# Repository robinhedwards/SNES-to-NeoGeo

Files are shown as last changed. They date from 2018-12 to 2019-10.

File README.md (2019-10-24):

SNES to Neo Geo
===============

This is an Arduino project which allows you to interface a SNES or Super Famicom controller
(or a clone) to a Neo Geo style DB15 connector.

I created this for my CMVS project (consolizing a MVS Neo Geo arcade motherboard), and I had
some nice, working SNES controllers that I wanted to use. SNES controllers are quite a good fit
for the Neo Geo because the button colours match (well, except on the purple USA ones!).

It looked easy enough to rewire the controllers and attach a new socket, but I wanted something
that left them in their original state so I could still use them on my SNES.

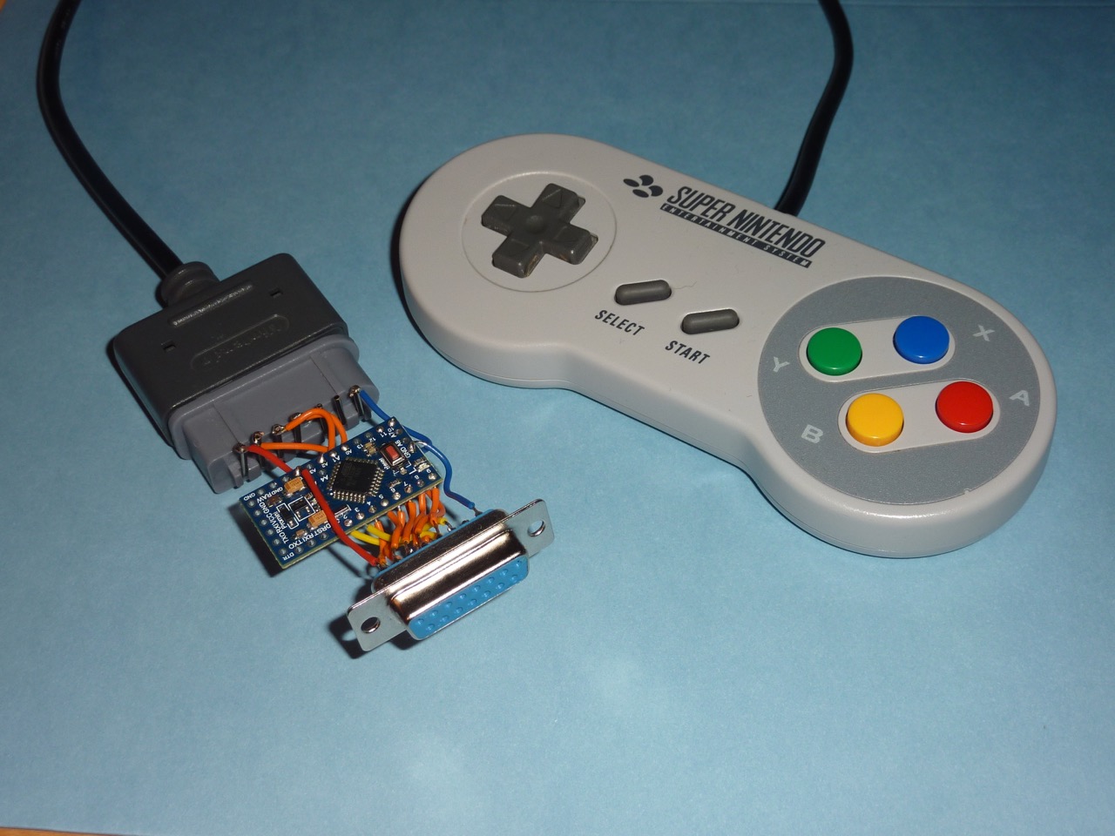
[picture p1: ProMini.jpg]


This shows a completed project on a cheap Arduino Pro Mini (5v) clone wired up to a SNES female
socket and female DB15 for easy connections.

SNES female controller sockets are available on eBay for a couple of pounds, and a Pro Mini
clone costs about the same, so the total cost of the project is only about five pounds.

SNES Controller -> Arduino
--------------------------

```
  -----------------\
  | 1 2 3 4 | 5 6 7 |
  -----------------/
  
  Pin 1: +5V
  Pin 2: Clock -> Arduino A0
  Pin 3: Latch -> Arduino A1
  Pin 4: Serial -> Arduino A2
  Pin 7: GND
```

Arduino -> DB15
---------------

```
    1(=GND)        8(=5V)
  \-------------------/
   \ o o o o o o o o / [Viewed from front]
    \ o o o o o o o /
     --------------- 
      9          15

 DB15 Pin  ->  Arduino
 --------      -------
 1 (GND)       GND
 8 (+5V)       +5V
 3 (Sel)       D2
 11 (Start)    D3
 15 (Up)       D4
 7 (Down)      D5
 14 (Left)     D6
 6 (Right)     D7
 13 (A)        D8
 5 (B)         D9
 12 (C)        D10
 4 (D)         D11
```

3d printed case
---------------

I've designed a simple box for the device that can be 3d printed. It fits the Pro Mini inside
along with the SNES socket and a cable grip for a DB15 cable.

The case is designed to fit a cable grip extracted from a UK mains plug (with 16mm spacing between
the grip screws).

The STL files are included here along with the source SCAD files if you need to make any tweaks to
the design.

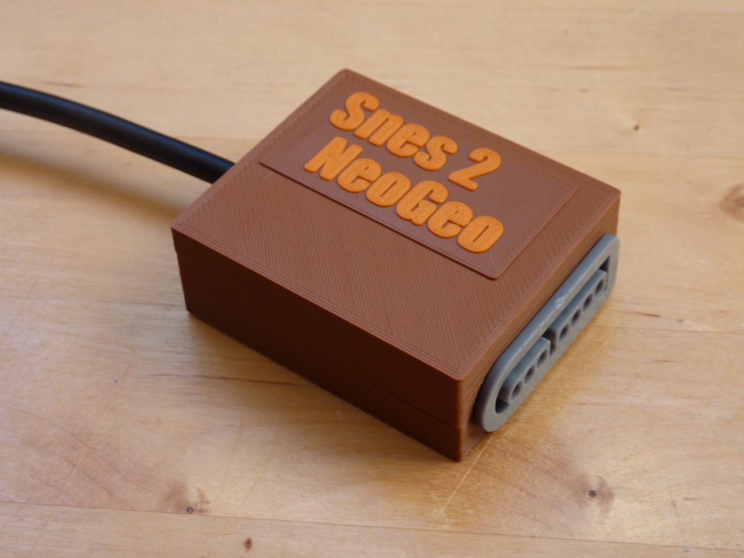
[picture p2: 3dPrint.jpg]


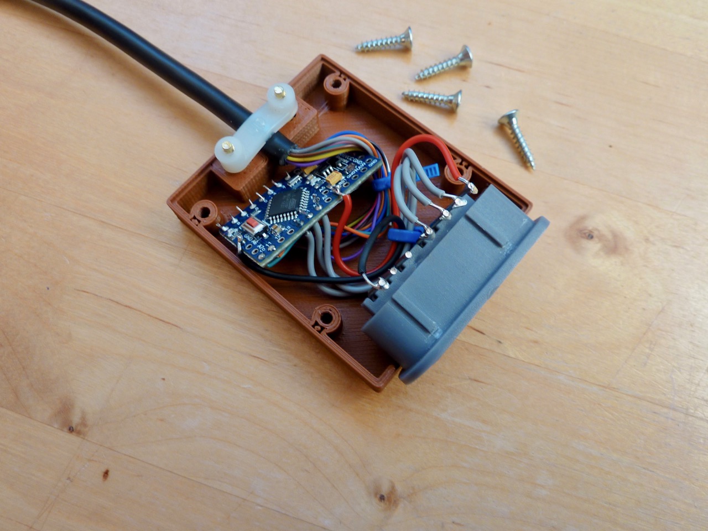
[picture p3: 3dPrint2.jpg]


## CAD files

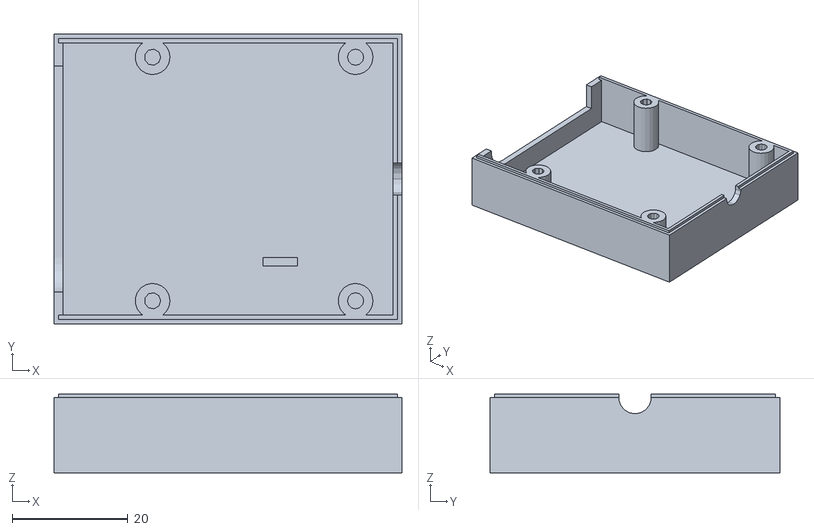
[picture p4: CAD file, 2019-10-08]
3d printing files/Snes2Neo_top.stl
60.0 x 50.0 x 13.6

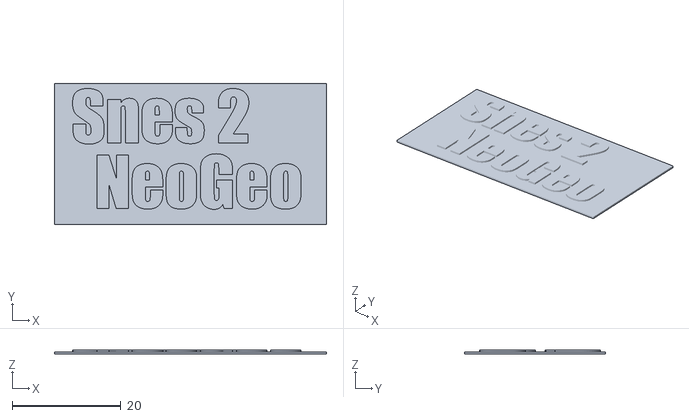
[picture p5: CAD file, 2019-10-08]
3d printing files/Snes2Neo_logo.stl
50.0 x 26.0 x 0.8

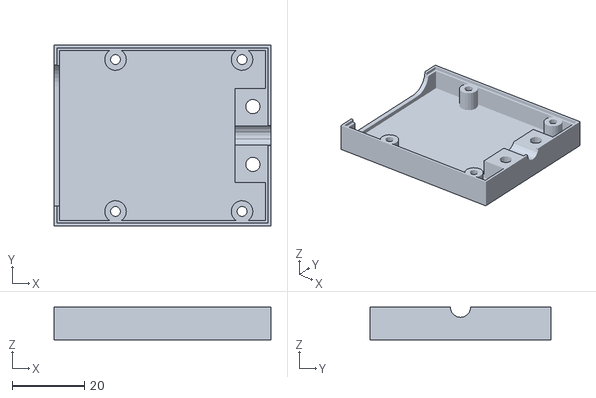
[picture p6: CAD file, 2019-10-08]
3d printing files/Snes2Neo_bottom.stl
60.0 x 50.0 x 9.00

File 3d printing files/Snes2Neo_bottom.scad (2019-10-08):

/* Snes 2 Neo Geo DB15 shell (bottom)
   (c) R.Edwards 2019
*/

cart_length=60; // 60
cart_width=50;
cart_height=9;
screw_sep = 39.5;
front_thickness = 1.6;
sides_thickness = 1.6 - 0.05;
rim_height = 1;
port_width = 39;
port_height = 12;
screw_radius = 3;
screw_from_edge = 1;

difference() {
    union() {
        difference() {
            // main shell
            cube([cart_length, cart_width, cart_height]);
            // rims
            translate([sides_thickness/2, sides_thickness/2, cart_height-rim_height])
                cube([cart_length-sides_thickness,
                    cart_width-sides_thickness, rim_height]);
            // make hollow
            translate([sides_thickness, sides_thickness, front_thickness])
                cube([cart_length-sides_thickness*2,
                    cart_width-sides_thickness*2,
                    cart_height-front_thickness]);
            // cutout snes port
            translate([0, (cart_width - port_width)/2, cart_height - port_height/2])
                translate([-sides_thickness/2, 0, 0])
                    union() {
                        cube([sides_thickness*2, port_width-port_height/2, port_height]);
                        translate([0,0,port_height/2])
                            rotate([0,90,0]) {
    //                            cylinder(h = sides_thickness*2, r1 = port_height/2, r2 = port_height/2,  $fs = 1);
                                translate([0, port_width-port_height/2, 0])
                                    cylinder(h = sides_thickness*2, r1 = port_height/2, r2 = port_height/2,  $fs = 1);
                            }
               }
        }
        translate([17, cart_width-screw_radius-screw_from_edge, 0])
            difference() {
                cylinder(h = cart_height-rim_height, r1 = screw_radius, r2 = screw_radius,  $fs = 1);
                cylinder(h = cart_height-rim_height, r1 = 1.8, r2 = 1.4,  $fs = 1);
            }
        translate([17, screw_radius+screw_from_edge, 0])
            difference() {
                cylinder(h = cart_height-rim_height, r1 = screw_radius, r2 = screw_radius,  $fs = 1);
                cylinder(h = cart_height-rim_height, r1 = 1.8, r2 = 1.4,  $fs = 1);
            }
        translate([52, cart_width-screw_radius-screw_from_edge, 0])
            difference() {
                cylinder(h = cart_height-rim_height, r1 = screw_radius, r2 = screw_radius,  $fs = 1);
                cylinder(h = cart_height-rim_height, r1 = 1.8, r2 = 1.4,  $fs = 1);
            }
        translate([52, screw_radius+screw_from_edge, 0])
            difference() {
                cylinder(h = cart_height-rim_height, r1 = screw_radius, r2 = screw_radius,  $fs = 1);
                cylinder(h = cart_height-rim_height, r1 = 1.8, r2 = 1.4,  $fs = 1);
            }
        // cable grip
        translate([50, (cart_width-26)/2, 0])
            cube([cart_length-50, 26, cart_height-rim_height]);
    }
    // cutout cable hole
    translate([cart_length-20, cart_width/2, cart_height])
        rotate([0,90,0])
            cylinder(h = 20, r1 = 2.8, r2 = 2.8,  $fs = 1);
    // screw top
    translate([17, cart_width-screw_radius-screw_from_edge, 0])
        cylinder(h = 0.6, r1 = 3.5, r2 = 3.5,  $fs = 1);
    translate([17, cart_width-screw_radius-screw_from_edge, 0.6])
        cylinder(h = front_thickness-0.6, r1 = 3.5, r2 = 1.8,  $fs = 1);
    translate([17, screw_radius+screw_from_edge, 0])
        cylinder(h = 0.6, r1 = 3.5, r2 = 3.5,  $fs = 1);
    translate([17, screw_radius+screw_from_edge, 0.6])
        cylinder(h = front_thickness-0.6, r1 = 3.5, r2 = 1.8,  $fs = 1);
    translate([52, cart_width-screw_radius-screw_from_edge, 0])
        cylinder(h = 0.6, r1 = 3.5, r2 = 3.5,  $fs = 1);
    translate([52, cart_width-screw_radius-screw_from_edge, 0.6])
        cylinder(h = front_thickness-0.6, r1 = 3.5, r2 = 1.8,  $fs = 1);
    translate([52, screw_radius+screw_from_edge, 0])
        cylinder(h = 0.6, r1 = 3.5, r2 = 3.5,  $fs = 1);
    translate([52, screw_radius+screw_from_edge, 0.6])
        cylinder(h = front_thickness-0.6, r1 = 3.5, r2 = 1.8,  $fs = 1);
    // holes for cable grip
    translate([55, cart_width/2-8, 0])
        cylinder(h = cart_height-rim_height, r1 = 2, r2 = 2,  $fs = 1);
    translate([55, cart_width/2+8, 0])
        cylinder(h = cart_height-rim_height, r1 = 2, r2 = 2,  $fs = 1);
    // screw tops
    translate([55, cart_width/2-8, 0])
        cylinder(h = 0.6, r1 = 3.5, r2 = 3.5,  $fs = 1);
    translate([55, cart_width/2-8, 0.6])
        cylinder(h = front_thickness-0.6, r1 = 3.5, r2 = 2,  $fs = 1);
    translate([55, cart_width/2+8, 0])
        cylinder(h = 0.6, r1 = 3.5, r2 = 3.5,  $fs = 1);
    translate([55, cart_width/2+8, 0.6])
        cylinder(h = front_thickness-0.6, r1 = 3.5, r2 = 2,  $fs = 1);
    
}
//            cylinder(h = sides_thickness, r1 = port_height/2, r2 = port_height/2,  $fs = 1);

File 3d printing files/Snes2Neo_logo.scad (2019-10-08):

/* SNES2Neo shell top (logo)
   (c) R.Edwards 2018
*/

width=50;
height=26;
thickness=0.4;

union() {
    translate ([3,15,thickness]) {
        linear_extrude(height = 0.4) {
            text("Snes 2", font = "Impact:style=Regular", size = 9);
        }
    }
    translate ([3,3,thickness]) {
        linear_extrude(height = 0.4) {
            text("  NeoGeo", font = "Impact:style=Regular", size = 9);
        }
    }
    cube([width, height, thickness]);
}

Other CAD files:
3d printing files/Snes2Neo_top.scad

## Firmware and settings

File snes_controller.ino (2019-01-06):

/*
SNES -> Jamma/Neo Geo DB15
Robin Edwards 2018
based on the code found at https://github.com/burks10/Arduino-SNES-Controller
*/

/* 

SNES Controller -> Arduino
  -----------------\
  | 1 2 3 4 | 5 6 7 |
  -----------------/
  
  Pin 1: +5V
  Pin 2: Clock -> Arduino A0
  Pin 3: Latch -> Arduino A1
  Pin 4: Serial -> Arduino A2
  Pin 7: GND
*/

int DATA_CLOCK    = A0;
int DATA_LATCH    = A1;
int DATA_SERIAL   = A2;

/* 

Arduino -> DB15
    1(=GND)        8(=5V)
  \-------------------/
   \ o o o o o o o o / [Viewed from front]
    \ o o o o o o o /
     --------------- 
      9          15

 DB15 Pin  ->  Arduino
 --------      -------
 1 (GND)       GND
 8 (+5V)       +5V
 3 (Sel)       D2
 11 (Start)    D3
 15 (Up)       D4
 7 (Down)      D5
 14 (Left)     D6
 6 (Right)     D7
 13 (A)        D8
 5 (B)         D9
 12 (C)        D10
 4 (D)         D11
*/

#define PIN_SELECT  2
#define PIN_START   3
#define PIN_UP      4
#define PIN_DOWN    5
#define PIN_LEFT    6
#define PIN_RIGHT   7
#define PIN_BUT1    8
#define PIN_BUT2    9
#define PIN_BUT3    10
#define PIN_BUT4    11

#define PIN_LED      13

int buttons_state[12];  // B,Y,Sel,Start,U,D,L,R,A,X,L,R
int output_pins[12] = { PIN_BUT2, PIN_BUT3, PIN_SELECT, PIN_START, PIN_UP, PIN_DOWN,
                        PIN_LEFT, PIN_RIGHT, PIN_BUT1, PIN_BUT4, 0, 0 };
void setup ()
{
    pinMode(DATA_CLOCK, OUTPUT);
    digitalWrite (DATA_CLOCK, HIGH);
  
    pinMode(DATA_LATCH, OUTPUT);
    digitalWrite(DATA_LATCH, LOW);
    
    pinMode(DATA_SERIAL, INPUT_PULLUP);
    
    pinMode(PIN_LED, OUTPUT);
}

void loop ()
{
    // Read from the SNES controller
    
    /* Latch for 12us */
    digitalWrite(DATA_LATCH, HIGH);
    delayMicroseconds(12);
    digitalWrite(DATA_LATCH, LOW);
    delayMicroseconds(6);
    
    /* Read data bit by bit from SR */
    for (int i = 0; i < 16; i++) {
        digitalWrite(DATA_CLOCK, LOW);
        delayMicroseconds(6);
        if (i <= 11)
            buttons_state[i] = digitalRead(DATA_SERIAL);
        digitalWrite(DATA_CLOCK, HIGH);
        delayMicroseconds(6);
    }
    
    // Output the state on our DB15 output pins
    // pulling them low if the equivalent SNES button
    // is pushed
    for (int i = 0; i <= 11; i++)
    {
        if (output_pins[i] != 0)
        {
            if (!buttons_state[i])
            {
                digitalWrite(output_pins[i], LOW);
                pinMode(output_pins[i], OUTPUT);
            }
            else
                pinMode(output_pins[i], INPUT);            
        }
    }

    // Output select/coin button to built-in LED
    if (!buttons_state[2])
        digitalWrite(PIN_LED, HIGH);
    else
        digitalWrite(PIN_LED, LOW);
    
    delay(5);
}

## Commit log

2019-01-06 fix docs for D button (had the wrong DB15 pin)
    [snes_controller.ino]
2019-01-16 add 3d print pictures
2019-10-08 add 3d printing files
    [Snes2Neo_bottom.scad, Snes2Neo_bottom.stl, Snes2Neo_logo.scad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]
